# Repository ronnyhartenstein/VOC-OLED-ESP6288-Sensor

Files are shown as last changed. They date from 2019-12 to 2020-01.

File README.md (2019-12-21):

# Arduino: VOC Sensor

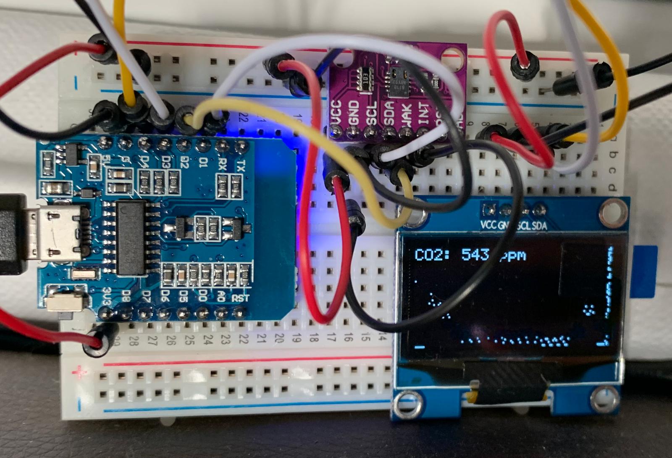
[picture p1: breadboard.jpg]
Breadboard Prototype


## Parts

### CCS811 VOC-Sensor
CJMCU-811 CCS811

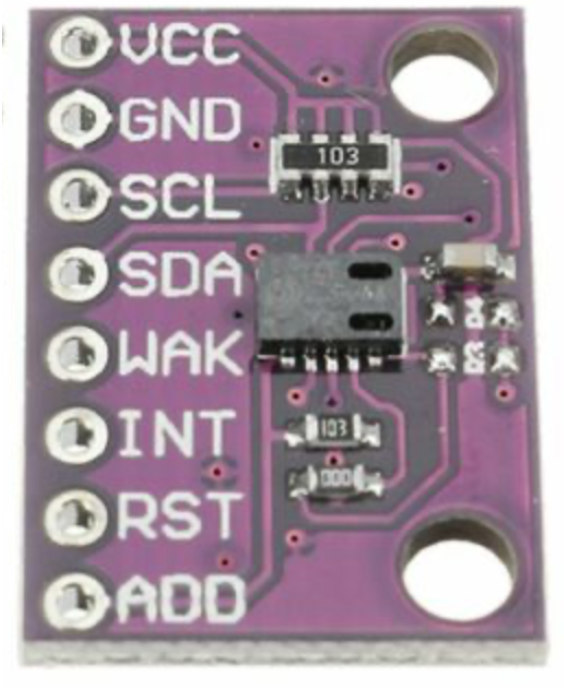
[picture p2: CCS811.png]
CCS811


https://revspace.nl/CJMCU-811
https://www.adafruit.com/product/3566

> “AMS recommends that you run this sensor for 48 hours when you first receive it to "burn it in", and then 20 minutes in the desired mode every time the sensor is in use. This is because the sensitivity levels of the sensor will change during early use.”

- TVOC -  Total Volatile Organic Compounds  - Gesamt flüchtige organische Verbindungen
- CO2 -- 400 ppm is baseline

### SH1106 OLED-Display
1,3"  SH1106 128x64 I2C

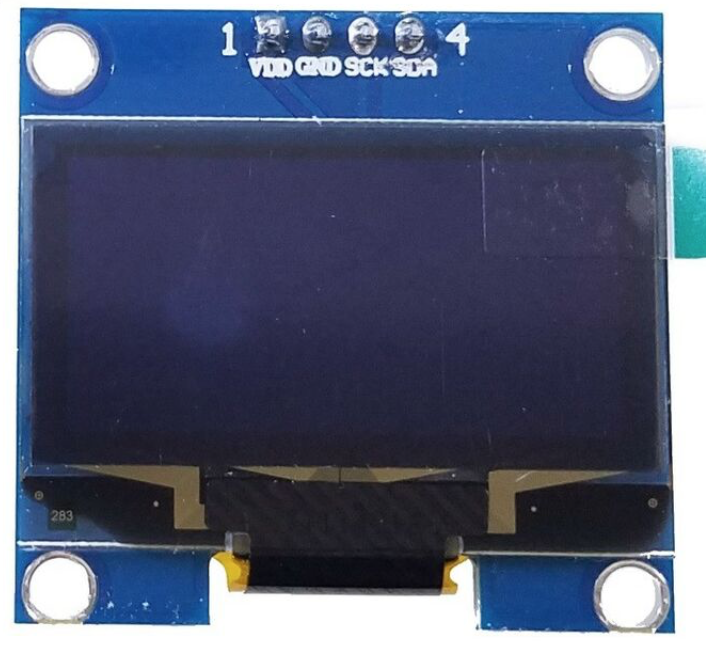
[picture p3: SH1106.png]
SH1106


Driver:
https://github.com/rene-mt/esp8266-oled-sh1106

Example:
https://github.com/rene-mt/esp8266-oled-sh1106/blob/master/examples/SH1106Demo/SH1106Demo.ino

“The SH1106 is in general similar to the SSD1306”

Normally it also works with 5V, but on breadboard it crashes, but not with 3,3V, so just use this.

## Prototype with Fritzing

https://steve.fi/Hardware/d1-pins/ 
SDA => D2
SCL => D1

https://projetsdiy.fr/test-du-ccs811-iaq-capteur-qualite-air-tcov-eco2-i2c-arduino-esp8266/

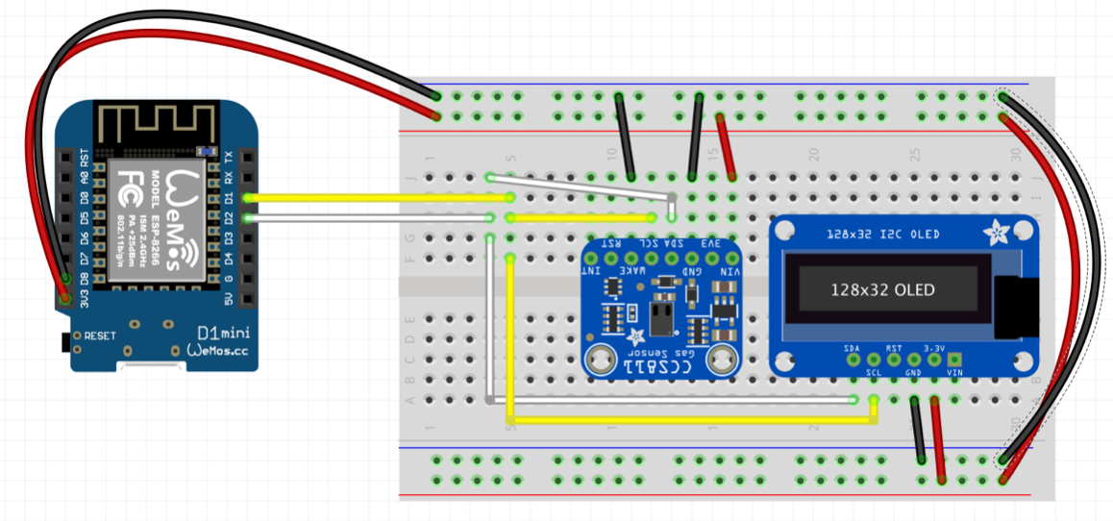
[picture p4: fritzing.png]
Layout with Fritzing


## Code
https://learn.adafruit.com/adafruit-ccs811-air-quality-sensor/arduino-wiring-test

I2C from OLED and VOC are separated, because VOC uses I2C clock stretching ([issue](https://github.com/adafruit/Adafruit_CCS811/issues/4
))

### SH1106 OLED

SDA -> D4
SDC -> D3

Addr: 0x3C

~~https://github.com/rene-mt/esp8266-oled-sh1106~~
~~I2C untested, don't work with it.~~

https://github.com/durydevelop/arduino-lib-oled

works with following setup:
OLED display = OLED(D4, D3, NO_RESET_PIN, 0x3C, 128, 64, true);

### CCS811 VOC-Sensor

SDA -> D2 (default)
SDC -> D1 (default)

Addr: 0x5A

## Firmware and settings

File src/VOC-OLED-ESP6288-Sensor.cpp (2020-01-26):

#include <SPI.h>
#include <Wire.h>
#include <Arduino.h>
#include <oled.h>
#include <ESP8266WiFi.h>

#include <Adafruit_MQTT.h>
#include <Adafruit_MQTT_Client.h>

#include <Adafruit_CCS811.h>

#include <DHT.h>

#include "Secrets.h"

#define I2C_SDA D4
#define I2C_SCL D3


// --------- VOC Sensor CCS811

Adafruit_CCS811 ccs;

// --------- Temperatur/Luftfeuchte DHD22

#define DHT22PIN D7
#define DHT22TYPE DHT22

DHT dht22(DHT22PIN, DHT22TYPE);


// --------- OLED Display SH1106

const int DISPLAY_BREITE = 128;
const int DISPLAY_HOEHE = 64;

// SDA, SCL, Reset PIN, I2C addr, width, height, isSH1106)
OLED display = OLED(I2C_SDA, I2C_SCL, NO_RESET_PIN, 0x3C, DISPLAY_BREITE, DISPLAY_HOEHE, true);

// --------- Display Render Steuerung

int y[DISPLAY_BREITE];
int x = 0;
int y_curr = 0;

int y_delta = 0;
float y_float = 0.0;

int eCO2_curr = 0;
int TVOC_curr = 0;

float temp_curr = 0.0;
float humi_curr = 0.0;

int loop_nr = 0;

#define ECO2_MIN 400
#define ECO2_MAX 5000

// -------- MQTT -------

WiFiClient client;

Adafruit_MQTT_Client mqtt(&client, MQTT_SERVER, MQTT_PORT, MQTT_USER, MQTT_KEY);

Adafruit_MQTT_Publish pub_voc_eco2 = Adafruit_MQTT_Publish(&mqtt, MQTT_USER "arduino/voc/eco2");
Adafruit_MQTT_Publish pub_voc_tvoc = Adafruit_MQTT_Publish(&mqtt, MQTT_USER "arduino/voc/tvoc");
Adafruit_MQTT_Publish pub_voc_temp = Adafruit_MQTT_Publish(&mqtt, MQTT_USER "arduino/voc/temp");

Adafruit_MQTT_Publish pub_baro_temp = Adafruit_MQTT_Publish(&mqtt, MQTT_USER "arduino/baro/temp");
Adafruit_MQTT_Publish pub_baro_humi = Adafruit_MQTT_Publish(&mqtt, MQTT_USER "arduino/baro/humi");

bool wlan_aktiv = false;

// ---------- Funktionen anmelden

void setup_voc_ccs811();
void setup_temp_dht22();
void setup_display_sh1106();
void setup_wifi();

void lese_voc_co2();
void lese_voc_tvoc();
void lese_voc_temp();
float lese_dht22_temp();
float lese_dht22_humi();
void publish_mqtt(Adafruit_MQTT_Publish pub, float val);
void x_erhoehen();
void display_rendern();
void MQTT_connect();

// ---------- SETUP --------

void setup() {
  Serial.begin(115200);
  delay(100);

  setup_voc_ccs811();
  delay(100);
  setup_temp_dht22();
  delay(100);
  setup_display_sh1106();
  delay(100);
  setup_wifi();
  delay(100);
}

void setup_voc_ccs811() {
  Serial.println("Starte VOC");
  if (!ccs.begin()) {
    Serial.println("Failed to start VOC Sensor CCS811!");
    while (1);
  }

  //calibrate temperature sensor
  Serial.println("Auf VOC warten");
  while (!ccs.available());

  Serial.println("Temperatur prüfen");
  float temp = ccs.calculateTemperature();
  ccs.setTempOffset(temp - 25.0);

  // am Anfang alle Sek.
  Serial.println("--> CSS Mode: 1 Sek");
  ccs.setDriveMode(CCS811_DRIVE_MODE_1SEC);
}

void setup_display_sh1106() {
  Serial.println("Starte Display");
  display.begin();
  // hinterhertreten, CCS811 arbeitet mit I2C clock stretching
  Wire.setClockStretchLimit(500);
}

void setup_temp_dht22() {
  Serial.println("Starte DHD22");
  dht22.begin();
}

void setup_wifi() {
  Serial.println("Verbinde mit WiFi SSID " + String(WLAN_SSID));

  WiFi.mode(WIFI_STA);
  WiFi.begin(WLAN_SSID, WLAN_PASSWORD);

  int versuch = 0;
  while (WiFi.status() != WL_CONNECTED) {
    delay(500);
    Serial.print(".");
    if (versuch == 10) {
      Serial.println(F("WLAN Verbindung fehlgeschlagen, dann eben ohne MQTT Publish"));
      break;
    }
    versuch++;
  }

  if (WiFi.status() == WL_CONNECTED) {
    wlan_aktiv = true;
    Serial.print("IP address: ");
    Serial.println(WiFi.localIP());
  }
}

// --------- LOOP ---------

void loop() {
  if (wlan_aktiv) {
    MQTT_connect();
  }

  temp_curr = lese_dht22_temp();
  humi_curr = lese_dht22_humi();

  int ccs_warte_zyklen = 10;
  while (!ccs.available()) {
    Serial.println("Auf VOC warten (loop) .. ");
    delay(500);
    if (ccs_warte_zyklen > 0) {
      ccs_warte_zyklen--;
    } else {
      return;
    }
  }

  Serial.println("CCS811: Setze Korrekturwerte: " + String(humi_curr) + " / " + String(temp_curr));
  ccs.setEnvironmentalData(humi_curr, temp_curr);
  if (!!ccs.readData()) {
    Serial.println("FEHLER!");
    while (1);
  }

  lese_voc_co2();
  lese_voc_tvoc();
  //lese_voc_temp();

  display_rendern();

  x_erhoehen();

  // ersten 10 Sek. alle 1 Sek messen
  if (loop_nr < 10) {
    delay(1100);
  }
  // nächste 50 Sek. alle 10 Sek messen
  else if (loop_nr < 10 + 5) {
    if (loop_nr == 10) {
      Serial.println("--> CSS Mode: alle 10 Sek");
      ccs.setDriveMode(CCS811_DRIVE_MODE_10SEC);
    }
    delay(11000);
  }
  // dann alle 60 Sek
  else {
    if (loop_nr == 15) {
      Serial.println("--> CSS Mode: alle 60 Sek");
      ccs.setDriveMode(CCS811_DRIVE_MODE_60SEC);
    }
    delay(61000);
  }
  // alle delays sind ein bisschen länger als der Loop -> https://github.com/adafruit/Adafruit_CCS811/issues/4#issuecomment-368252075
  loop_nr++;
}

/**
   CO2
   400 ppm -> y 0
   1000 ppm -> y 63 (Max)
*/
void lese_voc_co2()
{
  float eCO2 = ccs.geteCO2();
  eCO2_curr = abs(eCO2);
  if (eCO2_curr == 0) { 
    Serial.println(F("eCO2: 0 -> verwerfen"));
    return;
  }
  Serial.println("eCO2: " + String(eCO2_curr) + " ppm");
  if (eCO2_curr > 400) {
    publish_mqtt(pub_voc_eco2, eCO2_curr);
  }

  int y_delta = abs(eCO2) - 400;
  float y_float = (float) y_delta / (ECO2_MAX - ECO2_MIN);
  int y_curr = abs(y_float * (DISPLAY_HOEHE - 1));
  if (y_curr > (DISPLAY_HOEHE - 1)) {
    y_curr = DISPLAY_HOEHE - 1;
  }
  y[x] = y_curr;

}

/**
   TVOC -  Total Volatile Organic Compounds  - Gesamt flüchtige organische Verbindungen
*/
void lese_voc_tvoc()
{
  float TVOC = ccs.getTVOC();
  TVOC_curr = abs(TVOC);
  if (TVOC_curr == 0) { 
    Serial.println(F("TVOC: 0 -> verwerfen"));
    return;
  }

  Serial.println("TVOC: " + String(TVOC_curr)  + " ppb");
  publish_mqtt(pub_voc_tvoc, TVOC);
}

/**
   ungefähre Temperatur
*/
void lese_voc_temp()
{
  float temp = ccs.calculateTemperature();

  Serial.println("Temp: " + String(temp) + " °C");
  publish_mqtt(pub_voc_temp, temp);
}

float lese_dht22_temp()
{
  float temp = dht22.readTemperature();

  Serial.println("DHT22 Temp: " + String(temp) + " °C");
  publish_mqtt(pub_baro_temp, temp);

  return temp;
}

float lese_dht22_humi()
{
  float humi = dht22.readHumidity();

  Serial.println("DHT22 Humi:" + String(humi) + " %");
  publish_mqtt(pub_baro_humi, humi);

  return humi;
}

void publish_mqtt(Adafruit_MQTT_Publish pub, float val)
{
  if (!wlan_aktiv) {
    return;
  }
  //Serial.print(F("\nPublish "));
  //Serial.print("...");
  if (! pub.publish(val)) {
    Serial.println(F("MQTT Publish Failed"));
  } else {
    //Serial.println(F("OK!"));
  }
}


void x_erhoehen()
{
  x++;
  if (x == 128) {
    x = 0;
  }
}

/**
   Gesammelte Werte auf OLED Display darstellen
   Screen komplett neu aufbauen
*/
void display_rendern()
{
  display.clear();

  // Kurve malen
  int tmp_x = 0;
  while (tmp_x < 128) {
    // invers
    display.draw_pixel(tmp_x, 63 - y[tmp_x]);
    tmp_x++;
  }

  // Werte ausschreiben
  display.setCursor(1, 1);
  display.print("CO2: " + (String) eCO2_curr + " ppm");

  display.setCursor(1, 14);
  char data[20];
  sprintf(data, "%.1f°C/%.1f%%", temp_curr, humi_curr);
  display.print(data);

  display.display();

}


void MQTT_connect() {
  int8_t ret;

  if (mqtt.connected()) {
    return;
  }

  Serial.print("Connecting to MQTT... ");

  uint8_t retries = 3;
  while ((ret = mqtt.connect()) != 0) { // connect will return 0 for connected
    Serial.println(mqtt.connectErrorString(ret));
    Serial.println("Retrying MQTT connection in 5 seconds...");
    mqtt.disconnect();
    delay(5000);
    retries--;
    if (retries == 0) {
      // basically die and wait for WDT to reset me
      while (1);
    }
  }
  Serial.println("MQTT Connected!");
}

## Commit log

2019-12-21 läuft
    [VOC-Sensor.fzz]
2020-01-18 Fritzing mit separaten I2C für CCS811
    [VOC-Sensor.fzz]
2020-01-21 Warten auf CCS wenn der trödelt
2020-01-21 Delays erhöht, damit CCS Zeit hat die Daten zu lesen
2020-01-26 Temp und Humi mit anzeigen
